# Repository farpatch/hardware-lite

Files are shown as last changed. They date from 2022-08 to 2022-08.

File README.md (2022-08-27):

# Farpatch Lite

A lite version of Farpatch -- a wireless debugger based on Black Magic Probe.

## Differences from the full version

* Farpatch Lite is smaller, and can fit into smaller areas
* There are no level shifters or voltage regulators -- your target MUST run at 3.3V!
* There are no damping resistors, which might affect signal integrity with the target
* There is no separate UART connector -- UART is integrated onto the SWD connector
* There is only one LED on the PCB

Farpatch Lite can be designed as a two-layer PCB, but a four-layer PCB stackup is preferred for signal integrity purposes.

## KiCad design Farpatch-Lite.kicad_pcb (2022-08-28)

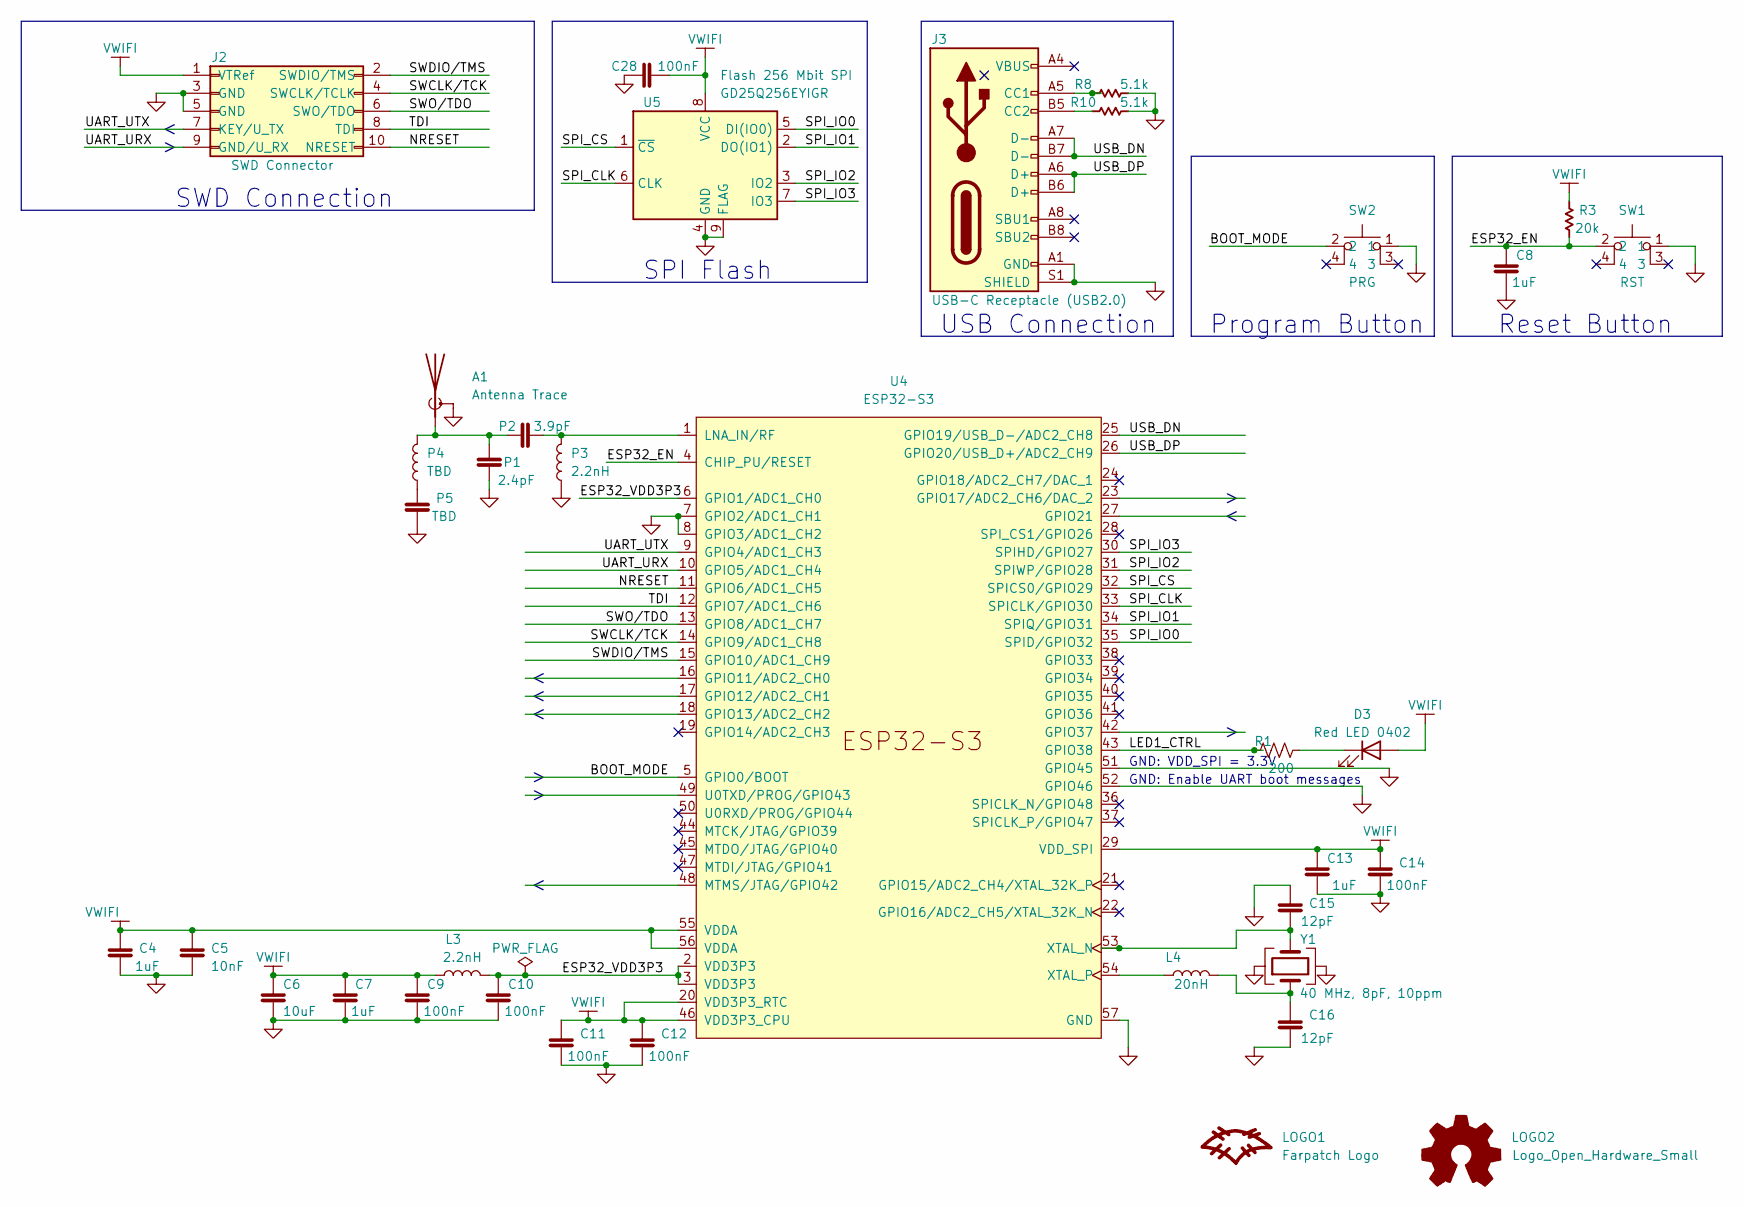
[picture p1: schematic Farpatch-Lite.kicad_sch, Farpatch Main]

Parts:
A1: Antenna Trace; Texas_SWRA117D_2.4GHz_Left
C4, C7, C8, C13: Cap 1uF 0402; C_0402_1005Metric; MFG PN ‎CL05A105MQ5NNNC‎
C5: Cap 10nF 0402; C_0402_1005Metric; MFG PN 885012205031
C6: Cap 10uF 0603; C_0603_1608Metric; MFG PN CL10A106KP8NNNC
C9, C10, C11, C12, C14, C28: Cap 100nF 0402; C_0402_1005Metric; MFG PN ‎CL05A104KA5NNNC‎
C15, C16: Cap 12pF 0402; C_0402_1005Metric; MFG PN ‎CC0402JRNPO9BN120‎
D3: Red LED 0402; LED_0402_1005Metric; MFG PN APHHS1005LSECK/J3-PF
J2: SWD Connector; PinHeader_2x05_P1.27mm_Vertical; MFG PN FTSH-105-01-F-DV-K
J3: USB-C Receptacle (USB2.0); USB_C_Receptacle_HRO_TYPE-C-31-M-12; MFG PN TYPE-C-31-M-12
L3: L 2.2nH 0402; L_0402_1005Metric; MFG PN LQW15AN2N2C10D
L4: L 20nH 0402; L_0402_1005Metric; MFG PN LQW15AN20NG00D
LOGO1: Farpatch Logo
LOGO2: Logo_Open_Hardware_Small; OSHW-Logo_5.7x6mm_SilkScreen
P1: Cap 2.4pF 0402; C_0402_1005Metric; MFG PN CC0402CRNPO9BN2R4
P2, P5: Cap 3.9pF 0402; C_0402_1005Metric; MFG PN CC0402CRNPO9BN3R9
P3, P4: L 2.7 nH 0402; L_0402_1005Metric; MFG PN L-07C2N7SV6T
R1: Res 200 0402; R_0402_1005Metric; MFG PN ‎RMCF0402JT200R‎
R3: Res 20k 0402; R_0402_1005Metric; MFG PN CR0402-FX-2002GLF
R8, R10: R 5.1k 0402; R_0402_1005Metric; MFG PN RMCF0402FT5K10
SW1, SW2: Pushbutton 4.2x3.2mm 250gf; SW_SPST_PTS810; MFG PN PTS810 SJK 250 SMTR LFS
U4: ESP32-S3; QFN-56-1EP_7x7mm_P0.4mm_EP5.6x5.6mm_ThermalVias; MFG PN ESP32-S3
U5: Flash 256 Mbit SPI; WSON-8_8x6mm_P1.27mm; MFG PN GD25Q256EYIGR
Y1: Crystal 40MHz 2016; Crystal_SMD_2016-4Pin_2.0x1.6mm; MFG PN XRCGB40M000F1S1BR0

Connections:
/BOOT_MODE: SW2.2, U4.5 (GPIO0/BOOT)
/ESP32_EN: C8.1, R3.1, SW1.2, U4.4 (CHIP_PU/RESET)
/ESP32_VDD3P3: C10.1, L3.2, U4.2 (VDD3P3), U4.3 (VDD3P3), U4.6 (GPIO1/ADC1_CH0)
/LED1_CTRL: R1.1, U4.43 (GPIO38)
/NRESET: J2.10 (NRESET), U4.11 (GPIO6/ADC1_CH5)
/SPI_CLK: U4.33 (SPICLK/GPIO30), U5.6 (CLK)
/SPI_CS: U4.32 (SPICS0/GPIO29), U5.1 (~CS)
/SPI_IO0: U4.35 (SPID/GPIO32), U5.5 (DI(IO0))
/SPI_IO1: U4.34 (SPIQ/GPIO31), U5.2 (DO(IO1))
/SPI_IO2: U4.31 (SPIWP/GPIO28), U5.3 (IO2)
/SPI_IO3: U4.30 (SPIHD/GPIO27), U5.7 (IO3)
/SWCLK/TCK: J2.4 (SWCLK/TCLK), U4.14 (GPIO9/ADC1_CH8)
/SWDIO/TMS: J2.2 (SWDIO/TMS), U4.15 (GPIO10/ADC1_CH9)
/SWO/TDO: J2.6 (SWO/TDO), U4.13 (GPIO8/ADC1_CH7)
/TDI: J2.8 (TDI), U4.12 (GPIO7/ADC1_CH6)
/UART_URX: J2.9 (GND/U_RX), U4.10 (GPIO5/ADC1_CH4)
/UART_UTX: J2.7 (KEY/U_TX), U4.9 (GPIO4/ADC1_CH3)
/USB_DN: J3.A7 (D-), J3.B7 (D-), U4.25 (GPIO19/USB_D-/ADC2_CH8)
/USB_DP: J3.A6 (D+), J3.B6 (D+), U4.26 (GPIO20/USB_D+/ADC2_CH9)
GND: A1.2 (Shield), C4.2, C5.2, C6.2, C7.2, C8.2, C9.2, C10.2, C11.2, C12.2, C13.2, C14.2, C15.1, C16.2, C28.1, J2.3 (GND), J2.5 (GND), J3.A1 (GND), J3.A12 (GND), J3.B1 (GND), J3.B12 (GND), J3.S1 (SHIELD), P1.1, P3.1, P5.1, R8.2, R10.2, SW1.1, SW2.1, U4.7 (GPIO2/ADC1_CH1), U4.8 (GPIO3/ADC1_CH2), U4.51 (GPIO45), U4.52 (GPIO46), U4.57 (GND), U5.4 (GND), U5.9 (FLAG), Y1.2, Y1.4
unnamed: A1.1 (A), P1.2, P2.1, P4.2
unnamed: C15.2, U4.53 (XTAL_N), Y1.3
unnamed: C16.1, L4.2, Y1.1
unnamed: D3.1 (K), R1.2
unnamed: J3.A5 (CC1), R8.1
unnamed: J3.A9 (VBUS), J3.B4 (VBUS)
unnamed: J3.B5 (CC2), R10.1
unnamed: L4.1, U4.54 (XTAL_P)
unnamed: P2.2, P3.2, U4.1 (LNA_IN/RF)
unnamed: P4.1, P5.2
VWIFI: C4.1, C5.1, C6.1, C7.1, C9.1, C11.1, C12.1, C13.1, C14.1, C28.2, D3.2 (A), J2.1 (VTRef), L3.1, R3.2, U4.20 (VDD3P3_RTC), U4.29 (VDD_SPI), U4.46 (VDD3P3_CPU), U4.55 (VDDA), U4.56 (VDDA), U5.8 (VCC)

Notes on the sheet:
Program Button
Reset Button
SWD Connection
GND: VDD_SPI = 3.3V
GND: Enable UART boot messages
SPI Flash
USB Connection

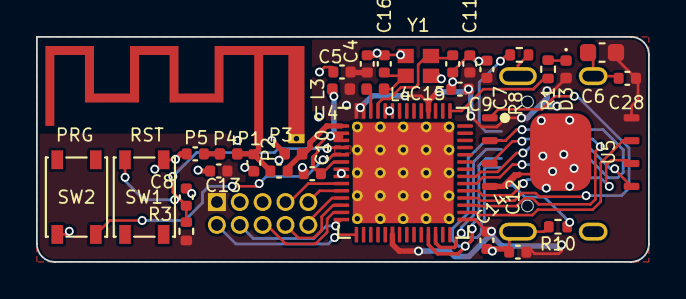
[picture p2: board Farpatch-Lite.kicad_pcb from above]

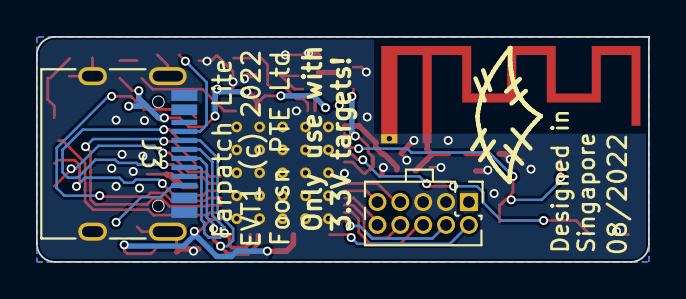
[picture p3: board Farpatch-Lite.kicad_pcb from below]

Board: 4 copper layers, 34.0 x 12.5 mm, 36 parts (3 on the bottom side), 31 nets.

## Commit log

2022-08-26 farpatch-lite: first draft
    [Farpatch-Lite.kicad_pcb, Farpatch-Lite.kicad_sch]
2022-08-26 farpatch-lite: Add fabrication data to PCB
    [Farpatch-Lite.kicad_pcb]
2022-08-27 farpatch: finish layout and update README
    [Farpatch-Lite.kicad_pcb, Farpatch-Lite.kicad_sch]
2022-08-28 evt1: switch to 4-layer PCB
    While it's possible to route the board in two layers, four layers
    are more reliable.
    [Farpatch-Lite.kicad_pcb]

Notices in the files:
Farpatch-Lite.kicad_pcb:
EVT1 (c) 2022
